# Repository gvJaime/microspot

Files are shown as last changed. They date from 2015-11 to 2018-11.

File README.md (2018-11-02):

# Microspot Project

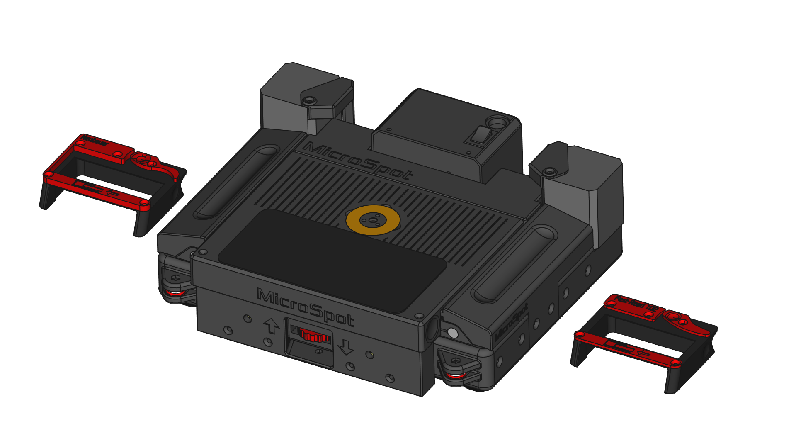
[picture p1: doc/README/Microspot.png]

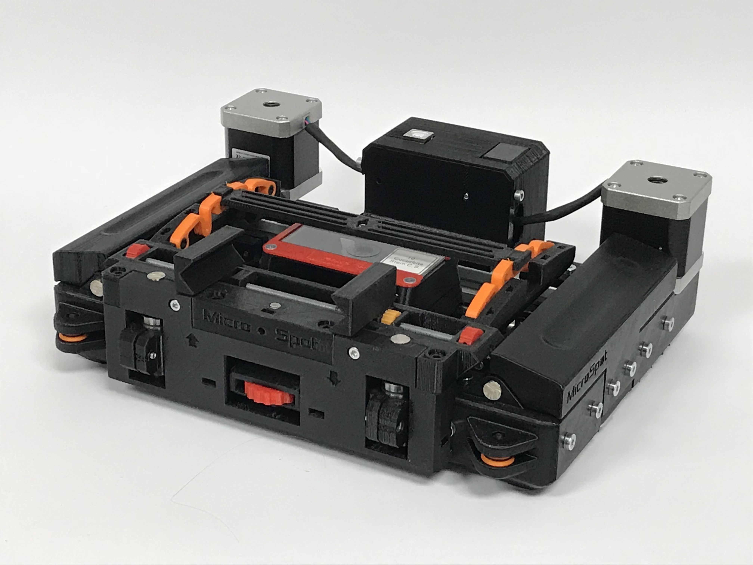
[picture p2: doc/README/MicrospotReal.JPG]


## Abstract

The purpose of this work is the development of a 3D printable, low cost, phone controlled, portable automated microscope that can be used to diagnose global health diseases anywhere in the world.

## The project

The device consists of a core-H mechanical stage, plus a vertical axis with a phone attached. The phone camera sees through an optical system that allows it to take pictures at a microscopic scale.

This project aims to bring medical diagnosis equipment to the open source community: Designs are made with 3D printing in mind, materials are inexpensive, and electronics accesible. The source is open from the very development stage, and the tools used to design it are open source.

This repo started as a collaboration between the Innovation and Robotics department of bq and the Technical University of Madrid, and it has been developed to a mature state within SpotLab S.L., but you can also contribute to it's development!

## Building the device

To build this device, you need to 3D print the objects indicated as "Printed" in the Assembly, and get all the items listed in the bill of materials.

+ Those groups labeled as PrintedStructural must be printed in a material that is considered suitable for structural applications. The rule of thumb is "the tougher the better".
+ Those groups labeled as PrintedTribologic must be printed in a material that holds at least some tribologic properties. They must present low friction.
+ Those gropus labeled as PrintedFlexible must be printed in flexible material.

The best way to understand how the device is made is to explore the Assembly file. Although, bill of materials and assembly instructions may be provided in the wiki.

## About this repository
This repository holds the mechanical information of the device, and wiki. Android app information and firmware information are held in other repos.

* `Mechanical`: [FreeCAD][FreeCADlink] files for the mechanical design
	* `src`: Source files in .FCStd format.
	* `Step`: Step files for component and auxiliar assembly import.
* `Optical` : Lens adapters approved on field.
* `Tools` : Tool parts that you may need for assembly or servicing.
* `Fonts`: Fonts used in the design of the parts.
* `doc`: useful files for documentation

### Contributing to this repository. Developer notes

You can contribute to this repo by forking it, and making pull requests to the [Development branch][Develop]. If you find problems to make the contribution this way, [place an issue][issue] and we'll work it out.

Due to FCStd files being unmergeable, Assembly.FCStd is modified only on the Development branch. It may not be included in pull requests.

**This repo relies heavily on [@hamish_2014 's Assemblyv2 workbench][Assemblyv2Link].** The assembly file is composed almost entirely of Assemblyv2 objects, every file has reference items that are imported dynamically using this workbench. **These files may not be usable if your FreeCAD distribution doesn't have this workbench installed.**

Also, there may be files that use [@DeepSOIC 's Lattice2 workbench][LatticeLink]'s Recompute locker. This may be used to avoid FreeCAD to recompute a whole file each time an operation is readjusted.

## History

### Microspot v0.1

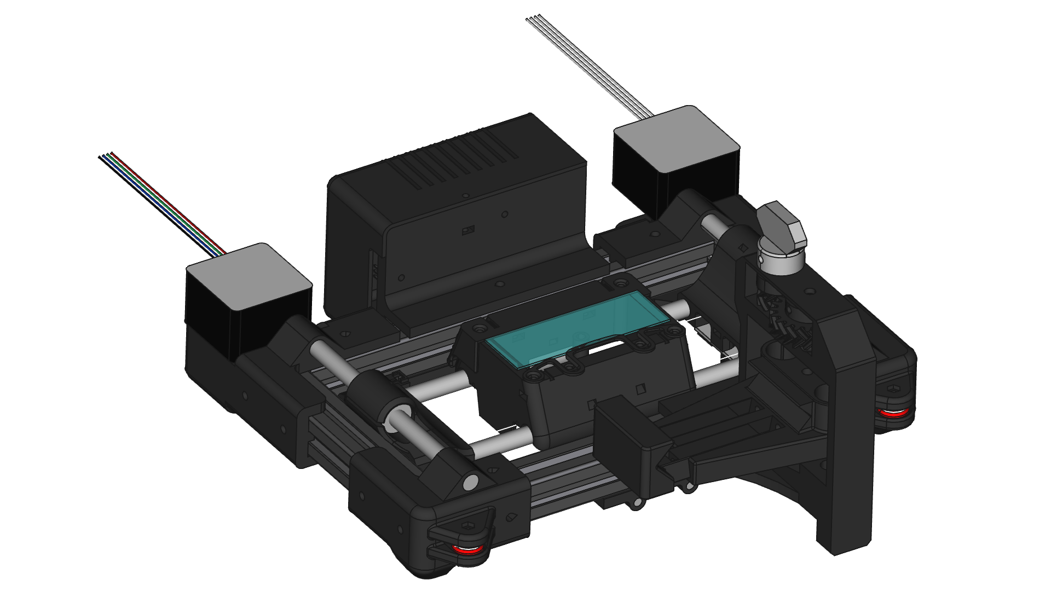
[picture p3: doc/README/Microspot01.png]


#### Changelog

+ Compact design, (256x256x130mm) for easy transport.
+ Aluminum profile + 3D printed parts based frame.
+ 2 axis core-H cartesian mechanical stage controlled by an Arduino, running [GRBL based firmware][microspot-fw].
+ 50x15mm scan area.
+ Integrated LED illumination system, with regulable intensity by firmware.
+ Phone support with adaptable grip, to fit all phone sizes.

### MicroSpot v0.2.1

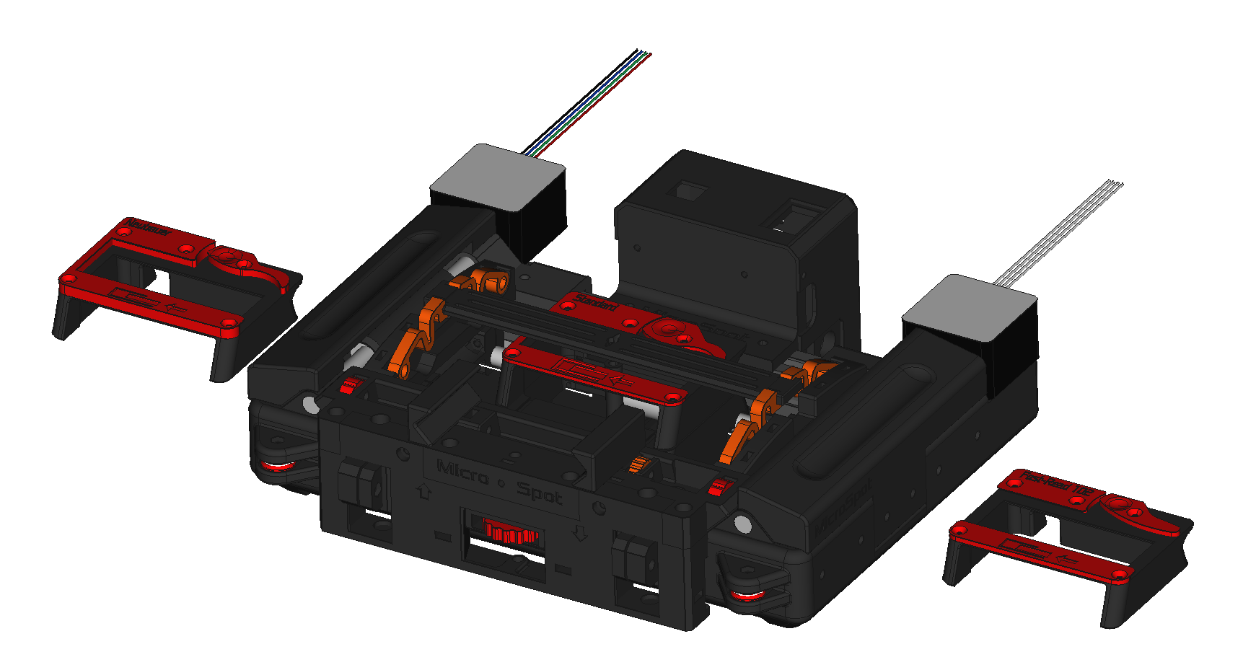
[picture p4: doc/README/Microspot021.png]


#### Changelog

+ New compact phone crane that doesn't stick forward, reducing size to 256x200x75
+ Lower plate protecting mechanical system.
+ Lens system adaptable for every phone.
+ New carriage design that allows for detachable sample trays.
+ Sample trays for standard samples, Neubauer samples, and more.
+ Sample fixing system revisioned.
+ General usability upgrades.

### MicroSpot v0.3

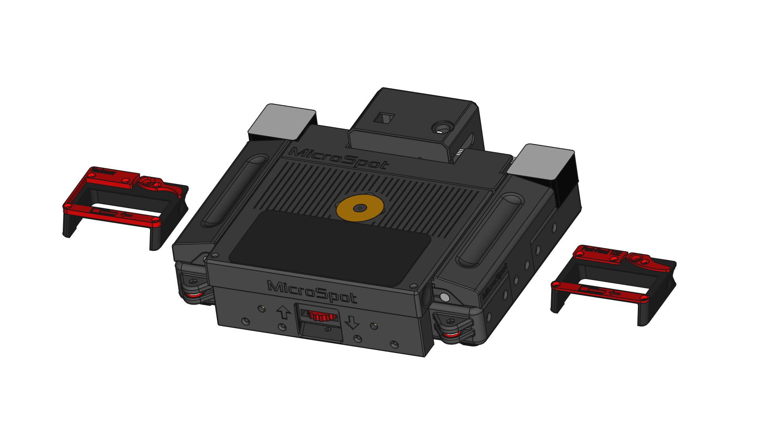
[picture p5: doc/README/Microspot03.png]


#### Changelog

+ New upper lid to protect the sample while scanning, featuring:
	+ New fixing system for the optics.
	+ New gel pad based fixing system for the phone.
	+ Openable by sliding forwards, allowing sample change without removing the phone.
	+ Stays closed by magnets.
+ Vertical axis revisioned.
	+ Printable linear guides, with BBs as bearings
	+ Updated knob, designed to minimize vertical backlash and ensure smooth movement.
+ Sample fixing system revisioned.
+ General assembly revisions.

### MicroSpot v1.0



#### Specs

+ New Optics system
	+ Capable of 10x.
	+ Tested on field.
+ New electronics.
+ General usability updates.
	+ New back lids that prevent mechanical damage to cables.
	+ Added On/Off switch.

## Credits

* SpotLab S.L. (Main Sponsor)
	* [@gvJaime](https://github.com/gvJaime) (Lead mechanical designer and integrator)
	* [@alexx666](https://github.com/alexx666) (Lead firmware programmer and connections coordinator.)
	* [@Dani-x2](https://github.com/Dani-x2) (Main Software Developer)
* Technical University of Madrid (Main concept & inspiration)
	* [@gvJaime](https://github.com/gvJaime) (Lead mechanical designer and researcher)
* Mundo Reader S.L (sponsor from October 2015 to April 2016)
	* [@gvJaime](https://github.com/gvJaime) (Lead mechanical designer and researcher)
	* [@AngelLM](https://github.com/AngelLM) (Mechanical designer. Wonderful teammate)

## License

Copyright (c) Universidad Politecnica de Madrid 2015

Licensed under Creative Commons 4.0 Attribution Share-Alike

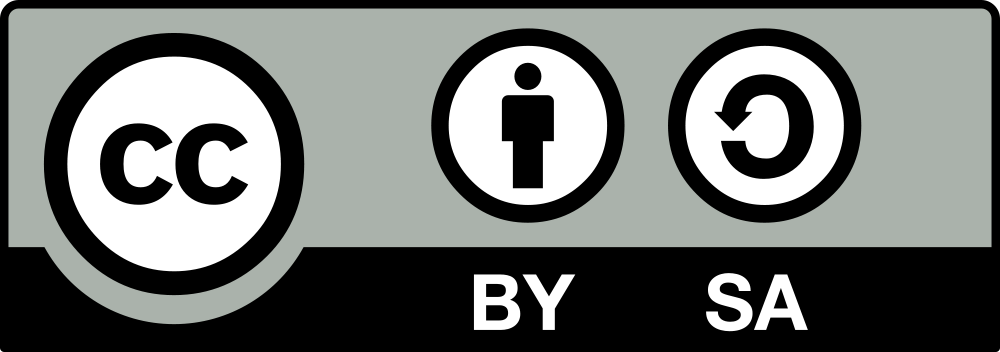
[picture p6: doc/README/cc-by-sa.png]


[FreeCADlink]: http://www.freecadweb.org/
[MalariaLink]: http://malariaspot.org/
[issue]: https://github.com/malariaspot/microspot/issues/new
[Develop]: https://github.com/malariaspot/microspot/tree/Development
[microspot-fw]: https://github.com/malariaspot/microspot-fw
[Assemblyv2Link]: https://github.com/hamish2014/FreeCAD_assembly2
[LatticeLink]: https://github.com/DeepSOIC/Lattice2

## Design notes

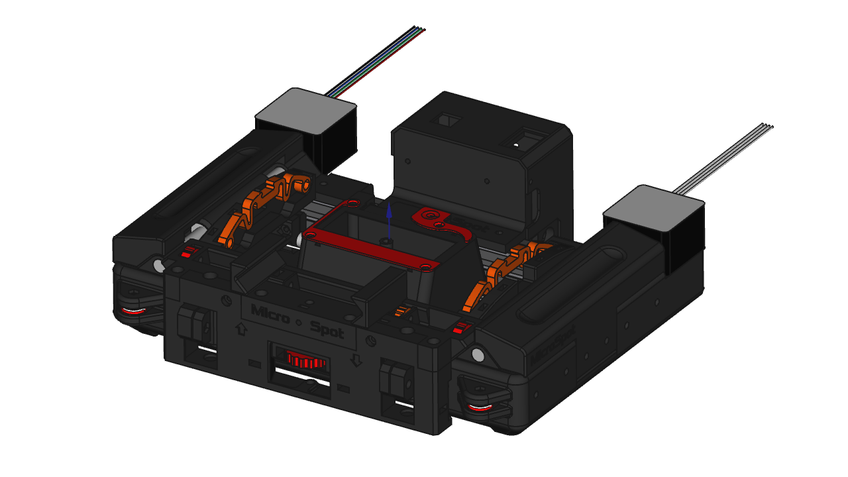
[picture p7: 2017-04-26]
doc/README/Microspot02.png

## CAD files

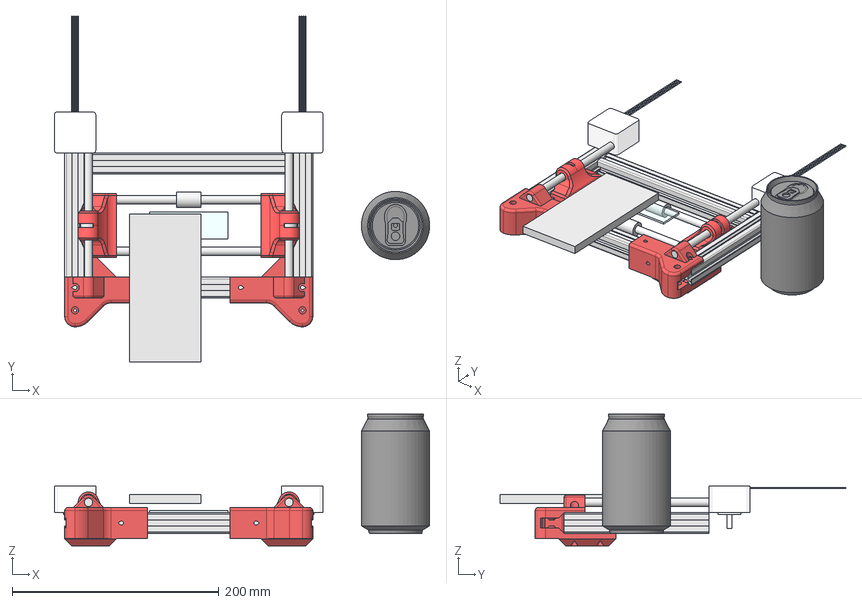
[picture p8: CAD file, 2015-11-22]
Mechanical/Assembly.fcstd
363.1 x 334.7 x 127.2 mm
T slot extrusion 20x20x200.001
T slot extrusion 20x20x140.001
Sample
bq Aquaris M5 Phone
4018X SNGL
YBar
XBar
LM8UU
LM8UU001
T slot extrusion 20x20x200.001 (Mirror #1)
T slot extrusion 20x20x140.001 (Mirror #2)
XBar (Mirror #4)
YBar (Mirror #5)
LM8UU (Mirror #6)
LM8UU001 (Mirror #7)
623ZZ (Mirror #9)
623ZZ (Mirror #10)
4018X SNGL (Mirror #3)
BeverageCan
623ZZ
623ZZ (Mirror #8)
Ycarriage
Ycarriage (Mirror #11)
IdlerHold
IdlerHold (Mirror #12)

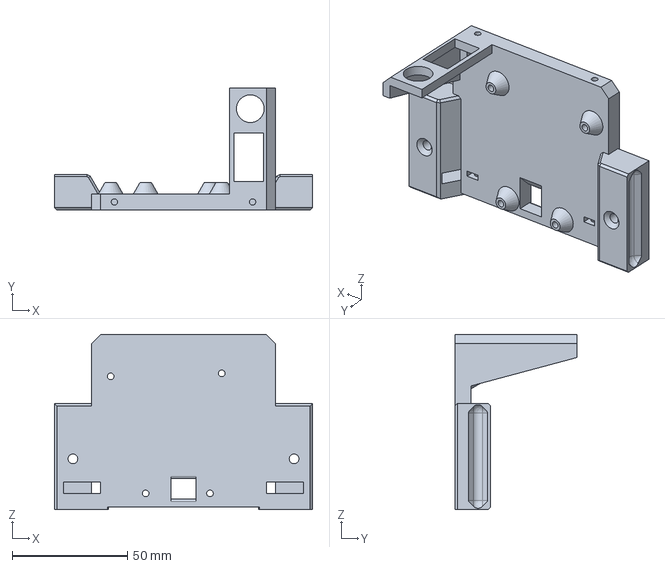
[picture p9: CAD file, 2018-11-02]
Mechanical/src/Electronics Holder/ElecMain.fcstd
112.0 x 53.0 x 76.0 mm

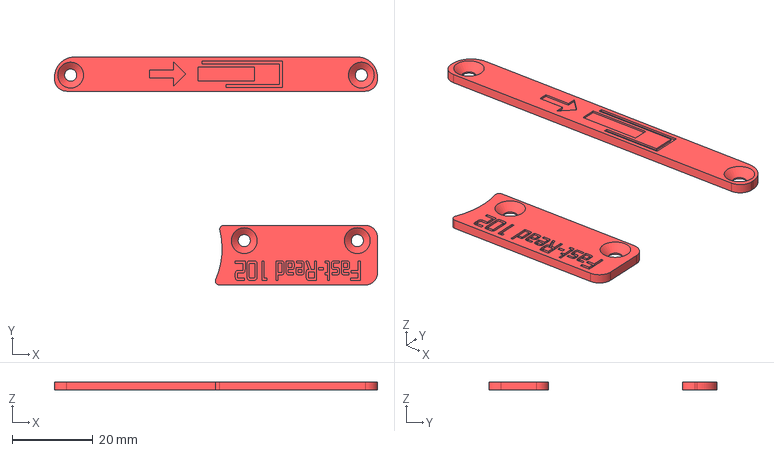
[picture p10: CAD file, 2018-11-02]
Mechanical/src/Axes/XCarriage/FastRead102/FastReadTop.fcstd
80.0 x 56.5 x 2.00 mm

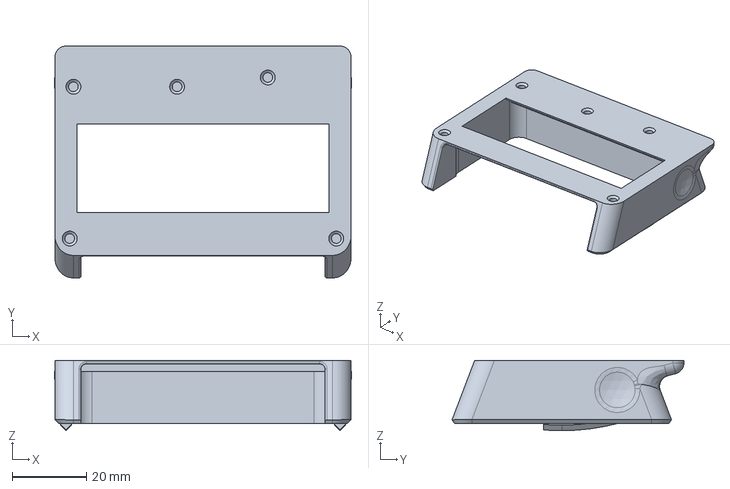
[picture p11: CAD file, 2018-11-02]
Mechanical/src/Axes/XCarriage/Neubauer/NeubauerTray.fcstd
80.2 x 62.6 x 19.0 mm

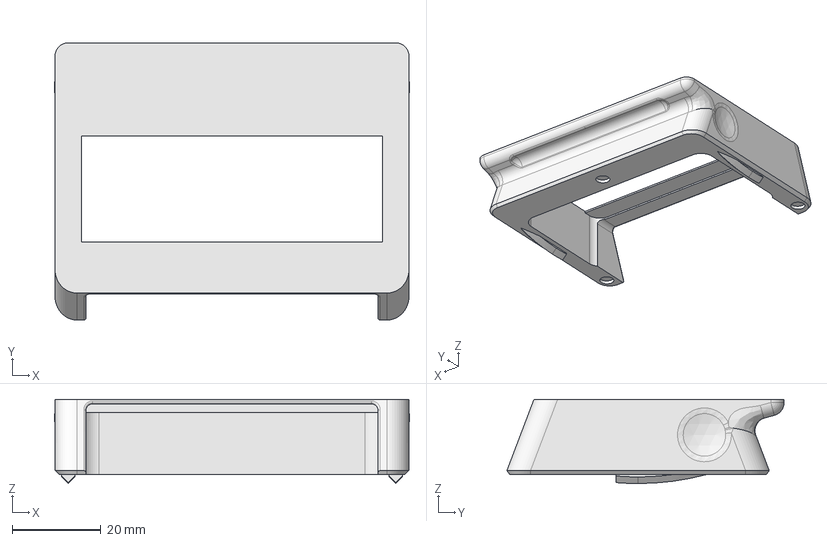
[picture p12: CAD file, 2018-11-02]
Mechanical/src/Axes/XCarriage/SampleTray.fcstd
80.2 x 62.6 x 19.0 mm

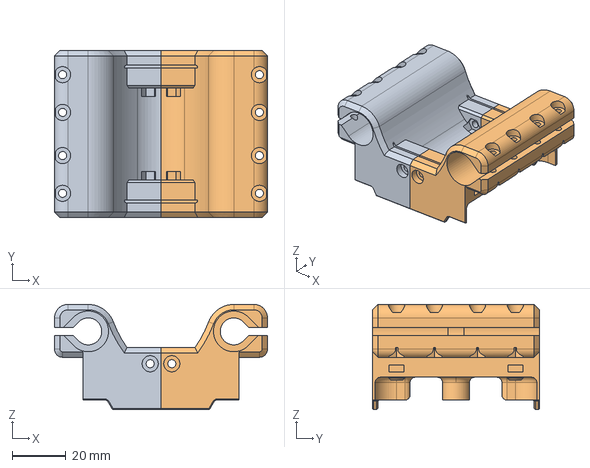
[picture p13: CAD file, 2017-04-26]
Mechanical/src/Axes/YCarriage/YCarriage.fcstd
79.0 x 62.0 x 39.0 mm
LYCarriage
RYCarriage

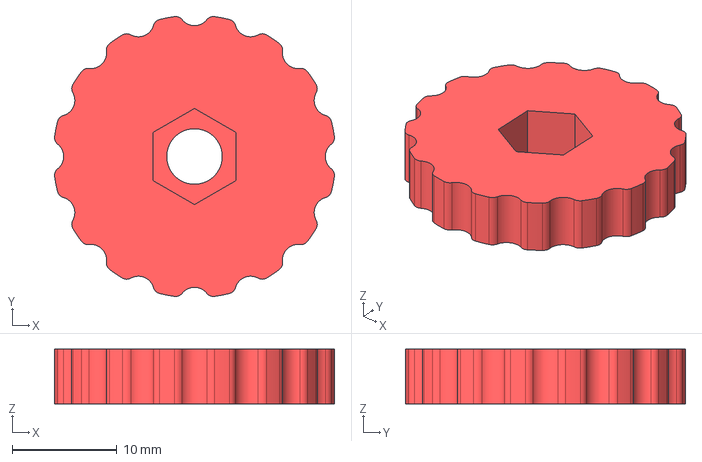
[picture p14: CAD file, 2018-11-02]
Mechanical/src/Axes/ZCarriage/FocusWheel.fcstd
26.7 x 26.7 x 5.25 mm

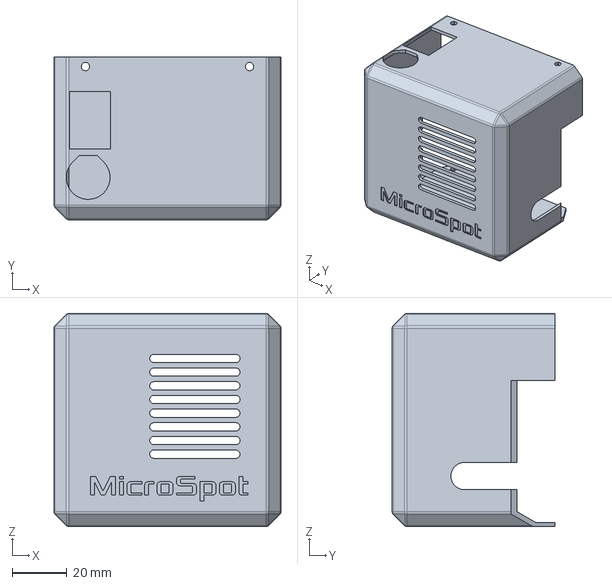
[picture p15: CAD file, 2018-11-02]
Mechanical/src/Electronics Holder/ElecLid.fcstd
83.0 x 59.5 x 78.0 mm

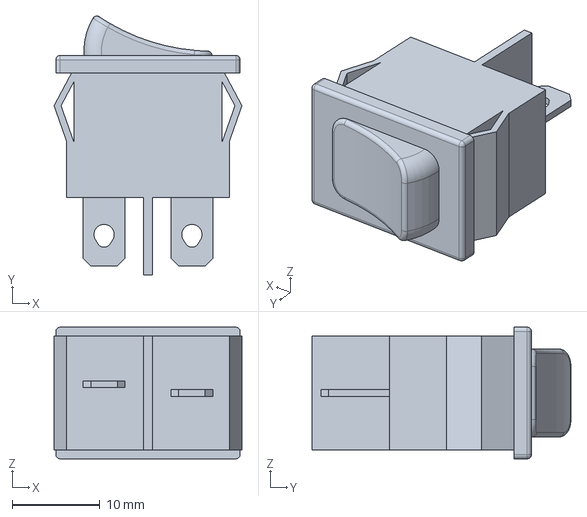
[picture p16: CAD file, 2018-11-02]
Mechanical/src/Electronics Holder/Reference/RLEIL RL3-4T125 55.fcstd
21.4 x 29.5 x 15.0 mm

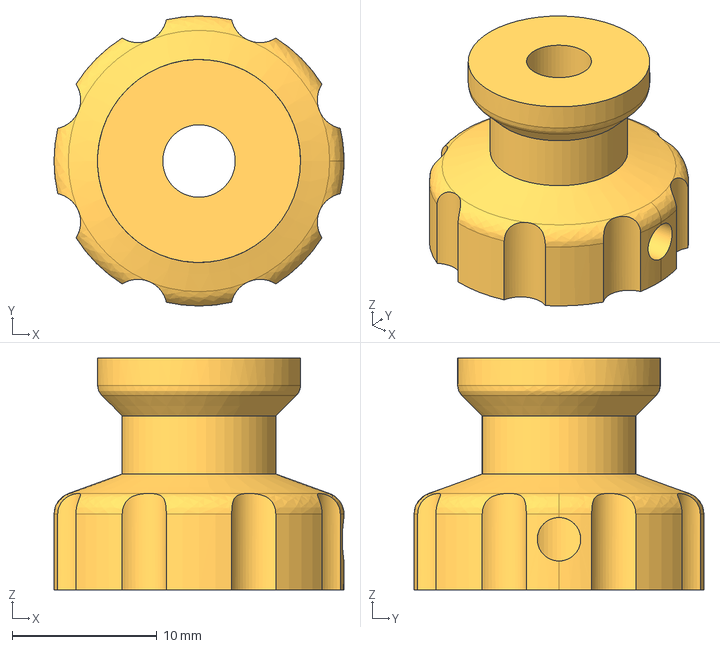
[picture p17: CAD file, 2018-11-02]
Mechanical/src/MainFrame/NEMAPulley.fcstd
20.0 x 20.0 x 16.0 mm

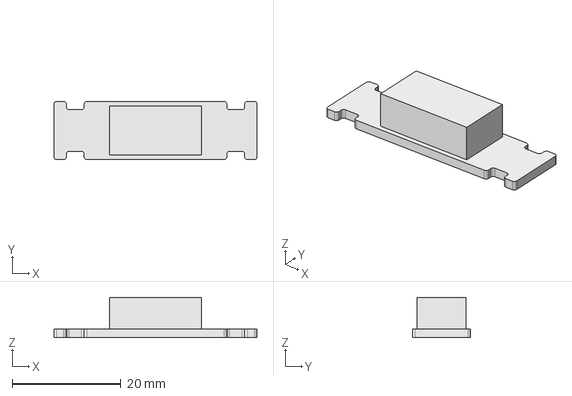
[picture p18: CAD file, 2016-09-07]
Mechanical/src/MainFrame/Reference/FemtoBuck.fcstd
37.4 x 10.7 x 7.38 mm

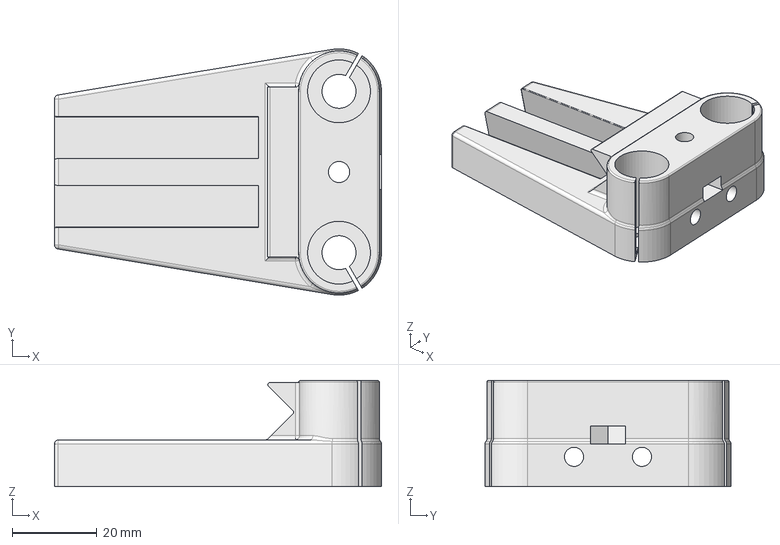
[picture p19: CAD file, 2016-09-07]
Mechanical/src/smartphoneHolder/PhoneCarriage.FCStd
77.0 x 58.0 x 25.0 mm

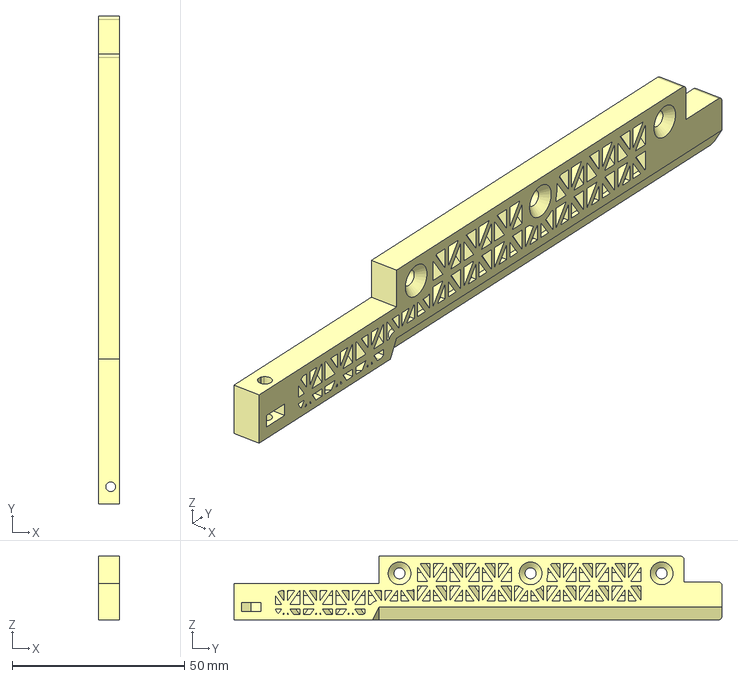
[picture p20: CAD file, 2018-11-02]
Mechanical/src/UpperLid/UpperLidRail.fcstd
6.00 x 141.5 x 18.5 mm

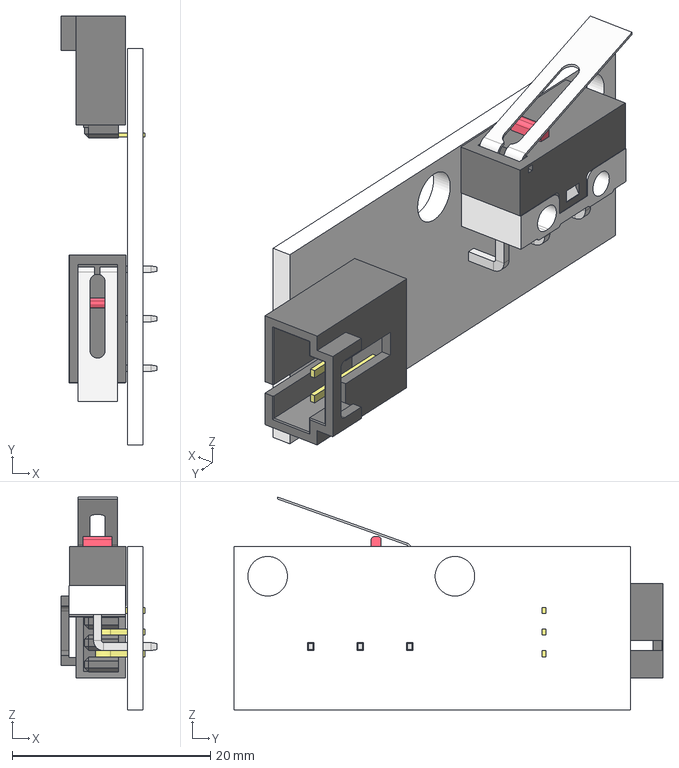
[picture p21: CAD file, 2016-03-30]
Mechanical/Step/Components/Endstop.step
9.70 x 43.3 x 21.5 mm

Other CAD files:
Mechanical/src/Axes/XCarriage/StdTray/StdTray.fcstd
Mechanical/Step/Printed/Axes/YCarriage/LYCarriage.step
Mechanical/Step/Printed/Axes/ZAxis/BackCraneGuide.step
Mechanical/Step/Printed/Electronics Holder/ElecBase.step
Mechanical/Step/Components/4018X SNGL.stp
Mechanical/Step/Components/NEMA8x13.step
Mechanical/Step/Printed/Axes/YCarriage/RYCarriage.step
Mechanical/Step/Printed/Axes/ZAxis/FrontCraneGuide.fcstd
Mechanical/Step/Printed/Axes/ZAxis/FrontCraneGuide.step
Mechanical/Step/Printed/Electronics Holder/Lid.step
Mechanical/Step/Printed/MainFrame/LAxisShield.step
Mechanical/Step/Printed/MainFrame/LBackCorner.step
Mechanical/Step/Printed/MainFrame/TubeLid.step
Mechanical/Step/Printed/PhoneHolder/Ratchet.step
Mechanical/Step/Printed/SmartphoneHolder/LPhoneGrip.step
Mechanical/Step/Printed/SmartphoneHolder/LowerPhoneCarriage.step
Mechanical/Step/Printed/SmartphoneHolder/RPhoneGrip.step
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

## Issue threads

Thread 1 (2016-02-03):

Y axis should have its bearings in triangle

elgambitero, 2016-02-03:
This prevents the carriage to lose perpendicularity with X axis

Closed 2016-02-15.

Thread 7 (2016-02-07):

NEMA doesn't fit in place

elgambitero, 2016-02-07:
The two metal frames are slightly wider than the plastic body that was taken as reference

Closed 2016-02-15.

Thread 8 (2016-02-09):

Front20Guide missing in IdlerHold

elgambitero, 2016-02-09:

Closed 2016-05-13.

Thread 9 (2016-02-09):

An UpperBolt missing in IdlerHold

elgambitero, 2016-02-09:

Closed 2016-05-13.

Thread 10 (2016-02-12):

Remodel Ycarriage in order to fix the bars to it better.

elgambitero, 2016-02-12:
It must feature a slot to let the plastic wrap around the smooth bar, tight.
It must feature a wall in the smooth bar hole, for it not to hit the idlers, and for ease of assembly.

Closed 2016-05-24.

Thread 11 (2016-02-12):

Rethink string lane geometries, in order to drive the string better upon assembly

elgambitero, 2016-02-12:
Make string size windows towards the pulleys. Idlers must be confined in a much smaller place. Idlers' geometry must trap the string, not letting it go that easily.

Something must be done to solve pulleys assembly. The string must be in tension all the time or it leaves the pulley!

Pulleys' shaft hole shape prevents it from going all the way down to the base of the NEMA and that's bad because the string can get trapped there if it unwraps the pulley.

elgambitero, 2016-05-10:
The new string configuration will take it through the center hole of the profiles, so we can use the outer surface for bolting. Also, that outer area doesn't have to be that thick.

With the extra bolts on the side, corners may be smaller, leaving more room for the phone crane to move.

So, motors have to be moved closer to each other, and also the front pulleys.

Closed 2016-06-08.

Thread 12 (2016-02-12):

Filaflex idlers could be absorbing some of the string tension.

gvJaime, 2016-02-12:

gvJaime, 2016-11-04:
This seems to be the reason there is a 0.2 mm backlash in the X axis.

gvJaime, 2017-01-18:
As it turns out, filaflex contributes for a smoother axis movement.

Closed 2017-02-17.

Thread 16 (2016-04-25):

Idler geometry doesn't hold the string in place

elgambitero, 2016-04-25:
String placement is extremely difficult.

elgambitero, 2016-05-24:
String placement is difficult for the FrontCorner idlers, but the YCarriage ones are just OK.
MainFrame remodellation may solve this.

elgambitero, 2016-06-08:
YCarriage idlers still suffer but assembly is acceptable. Making the pulleys larger could need mayor part update

Closed 2016-06-08.

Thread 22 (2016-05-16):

LEDTube is too narrow in its center part

elgambitero, 2016-05-16:

elgambitero, 2016-09-05:
With the new illuminator design, this issue doesn't make sense anymore.

Closed 2016-09-05.

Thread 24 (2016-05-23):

Decide a shape for smooth rod and bearing horizontal holes.

gvJaime, 2016-05-23:

gvJaime, 2016-10-04:
A good option is, the typical tear shape, but with an horizontal cut on the spike, at a distance from the center that is equal to the radius.

Closed 2016-10-20.

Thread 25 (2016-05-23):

PhoneCarriage needs to be iterated

elgambitero, 2016-05-23:

elgambitero, 2016-05-24:
M5 nut doesn't fit the slot.
Bearings sit with too much clearance, tighter slots and a expanding slit may solve the issue.
M3 threaded rod holes need to be wider in order to the rod passing through.
The platform needs to be longer. It will bend with bigger phones.

Closed 2016-06-08.

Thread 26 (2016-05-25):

When RYCarriage bearings are placed, they end up misaligned.

gvJaime, 2016-05-25:

elgambitero, 2016-05-25:
The bearing slit design tilts the bearings against the open side.

elgambitero, 2016-05-25:
With a little bit of sanding and 3D printing debris removal, this issue can be worked around.

Closed 2016-11-30.

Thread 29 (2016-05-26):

Light bounces on XCarriage inner walls and it may distort the image

elgambitero, 2016-05-26:

elgambitero, 2016-09-05:
With the install of the LED tube, this issue doesn't make sense anymore. Closing.

Closed 2016-09-05.

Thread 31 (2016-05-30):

Endstop bolt hole missing in BackCorner

elgambitero, 2016-05-30:

Closed 2016-06-10.

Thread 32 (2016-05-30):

Endstop bolt hole missing in BackCorner

elgambitero, 2016-05-30:

Closed 2016-05-30.

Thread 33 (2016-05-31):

Y Endstop pins collide with BackCorner.

gvJaime, 2016-05-31:

Closed 2016-10-07.

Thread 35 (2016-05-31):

String tensioner fixing bolt holes in XCarriage should be longer, not to require an excessive short bolt

elgambitero, 2016-05-31:

Closed 2016-05-31.

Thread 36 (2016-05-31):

Idlers collide with the cavity when spinning

elgambitero, 2016-05-31:

Closed 2016-06-08.

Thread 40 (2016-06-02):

Current string tensioner system can destroy the string.

elgambitero, 2016-06-02:

elgambitero, 2016-06-08:
Kevlar string can be crushed, but polyester string yields better results.

elgambitero, 2016-09-05:
Polyester strings doesn't break. It rather penetrates the threads of the nut, fixing itself in place.

Closed 2016-09-05.

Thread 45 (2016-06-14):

Electronics lid fixings are insufficient.

elgambitero, 2016-06-14:
The "one bolt" philosophy didn't quite work.

Closed 2016-06-20.

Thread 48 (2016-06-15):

Make PhoneCarriage reach lower positions.

elgambitero, 2016-06-15:
It must be able to almost collide with the sample, in cases of ball lens usage.

elgambitero, 2016-06-15:
Removing the upper cap, you can get the carriage 5mm lower in position

Closed 2016-07-06.

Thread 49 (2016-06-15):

SampleFix doesn't push hard enough against the sample

elgambitero, 2016-06-15:

Closed 2016-06-20.

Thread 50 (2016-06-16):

Make DVD lens adaptor for Aquaris X5

gvJaime, 2016-06-16:

elgambitero, 2016-06-16:
Aquaris X5 and Xperia X1 would be the first phones to recieve an adaptor design. For convenience.

elgambitero, 2016-06-17:
First print proved the design to be highly disfunctional

gvJaime, 2016-11-30:
Deprecated due to NewCrane

Closed 2016-11-30.

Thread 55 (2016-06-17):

Add bolts to XCarriage to guide SampleFix

elgambitero, 2016-06-17:

elgambitero, 2016-06-17:
Sample fix will need a redesign to accept this bolt usage.

Closed 2016-06-20.

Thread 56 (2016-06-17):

StringTensioner sample top is the wrong side.

gvJaime, 2016-06-17:

elgambitero, 2016-07-26:
This has turned up to be a problem upon usage in Mozambique.

Closed 2016-11-30.

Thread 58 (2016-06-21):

Phone Gears are placed too far from each other

elgambitero, 2016-06-21:

elgambitero, 2016-06-21:
This produces backlash, and hysteresis between the pinion spin and the vertical placement

elgambitero, 2016-06-22:
Bringing the gears too close together can led to jams.

Closed 2016-07-06.

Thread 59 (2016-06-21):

Phone gears' nut slot is too wide and lets the nut spin freely.

elgambitero, 2016-06-21:

Closed 2016-06-22.

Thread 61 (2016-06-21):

DVD2Xperia's camera hole is too high

elgambitero, 2016-06-21:

Closed 2016-06-22.

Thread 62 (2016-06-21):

PhoneHolder threaded rods need thumbscrews

gvJaime, 2016-06-21:

elgambitero, 2016-06-22:
Making the hole wider to meet tight tolerances was a mistake, because Slic3r already corrects this.
Making the hexagon dimensions nominal.

Closed 2016-11-30.

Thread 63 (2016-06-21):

When spinning, Phone gears teeth collide.

elgambitero, 2016-06-21:

elgambitero, 2016-06-21:
This will be tested when the new gears are properly printed.

Closed 2016-06-29.

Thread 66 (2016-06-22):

Make experimental scope with the two BluRay lenses

gvJaime, 2016-06-22:

elgambitero, 2016-06-22:
Refractive indices are needed for proper calculation.

elgambitero, 2016-06-22:
In case of not having proper index measurements, consider making a focusing mechanism, modifying the distance between the two lenses.

gvJaime, 2017-05-22:
This issue has been obsoleted by the preference of stock lenses, and the new "Snell law" command.

Version 0.3 issue #180 already counts on this.

Closed 2017-05-22.

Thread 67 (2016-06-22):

Make phone gears shaft emerge from protuberances, so the gears get aligned.

elgambitero, 2016-06-22:
Also, a little bit of friction could provide a more uniform progression of the axis, and give it strength not lose position because of vibrations.

Closed 2016-07-06.

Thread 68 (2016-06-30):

Update crane design to allow a Z motor to be installed.

elgambitero, 2016-06-30:
This is an update of the original design by @AngelLM, rather than a complete redesign needed for #54

Closed 2016-07-05.

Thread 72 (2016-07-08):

Illuminator doesn't fit between XCarriage domain and the ground

elgambitero, 2016-07-08:
Zip-ties collide
Min and Max Xcarriage points make endstop flaps collide.
Bolts collide with the floor, even when the stick out just the width of a nut.

Closed 2016-07-12.

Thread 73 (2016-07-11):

Xcarriage endstop flaps collide with illuminator

elgambitero, 2016-07-11:
They can be made 1 or 2 millimeters shorter, without compromising their function

Closed 2016-07-12.

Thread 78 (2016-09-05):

Add a lower panel to protect the axes and the string.

gvJaime, 2016-09-05:

elgambitero, 2016-09-05:
That could require, and benefit from, a complete frame redesign.

Closed 2016-10-07.

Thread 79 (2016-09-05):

Make multiphone adaptor for various lenses

elgambitero, 2016-09-05:

elgambitero, 2016-09-05:
It must have a sliding lens mount, so the user can select between various magnifications.
It must fit every phone (this is, every width, every thickness, and every camera position)

elgambitero, 2016-09-05:
A flexible design could be the solution, but that may give some difficulties with 3d printing, and durability of the part.

gvJaime, 2016-10-27:
The design is hard to print, and nails disassemble by themselves.

gvJaime, 2016-11-03:
See #105

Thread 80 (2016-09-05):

Redesign frame to make assembly easier

gvJaime, 2016-09-05:

elgambitero, 2016-09-05:
The assembly must be obvious, and must not require special skill.  It must be easily repeatable.

elgambitero, 2016-09-19:
The main difficulties of the current assembly are: fitting the two halves, and putting the string in place. The latter is way more complicated than the former.

Closed 2017-01-18.

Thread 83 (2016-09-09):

Attaching and adjusting the phone crane is painfully difficult

gvJaime, 2016-09-09:

gvJaime, 2016-12-09:
The new phone crane solved this issue. Disassembly is no longer needed before packaging the device.

Closed 2016-12-09.

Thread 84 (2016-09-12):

1mm Xperia adapter is too thin, and may slip or break

gvJaime, 2016-09-12:

Closed 2016-10-07.

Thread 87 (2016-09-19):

MainStructure of the phone holder won't reach the floor.

gvJaime, 2016-09-19:
Now that the MicroSpot frame is 3mm higher, this needs adjustment.

gvJaime, 2016-10-13:
With the new crane, this condition is no longer needed.

Closed 2016-12-09.

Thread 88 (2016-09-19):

Light is uneven across the field

gvJaime, 2016-09-19:
A flare that washes out the image can be seen through the sample. It is the center of the LED light source.

gvJaime, 2016-10-24:
Could a cigarette filter smooth the lightning enough?

Closed 2017-11-20.

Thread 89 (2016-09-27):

CNCShield doesn't power up the arduino

gvJaime, 2016-09-27:
This is a CNCShield design decision rather than a bug, but for MicroSpot is inconvenient because this make us rely on the phone to power up the arduino.

As tests with the OnePlus Two reveal, not every phone allows to output power over USB.

gvJaime, 2018-02-06:
A connecting the Vin Pin directly to 12V could work, but it would stress the voltage converter of the board.

gvJaime, 2018-11-05:
With the addition of Sparkfun's redboard, this is not an issue anymore.

Closed 2018-11-05.

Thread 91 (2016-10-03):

StringTensioner bolt needs another point of support

gvJaime, 2016-10-03:
The current setting results in backlash.

Closed 2016-11-30.

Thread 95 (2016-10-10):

MCNail in MultiClaw won't fit the rail.

gvJaime, 2016-10-10:

gvJaime, 2016-11-30:
Deprecated due to NewCrane

Closed 2016-11-30.

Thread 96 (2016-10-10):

MCGrip rail's walls are too thin

gvJaime, 2016-10-10:

gvJaime, 2016-11-30:
Deprecated due to NewCrane

Closed 2016-11-30.

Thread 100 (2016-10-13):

MainStructure doesn't fit for centered camera phones

gvJaime, 2016-10-13:
as v2Preview asssembly file reveals

gvJaime, 2016-11-30:
Deprecated due to NewCrane

Closed 2016-11-30.

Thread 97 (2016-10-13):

MechEndstop board sourcing is too difficult

gvJaime, 2016-10-13:
LBackCorner redesign might be in order, given the fact that it adjust to the board and the conector

gvJaime, 2016-10-13:
Migration to raw switches may need the edition of LBackCorner, RYCarriage, and in the event of changing the center position, the LowerCover

Closed 2016-11-14.

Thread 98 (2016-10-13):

MainStructure bolt orientation is wrong

gvJaime, 2016-10-13:

Closed 2016-10-20.

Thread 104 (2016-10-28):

Light tube is too short

gvJaime, 2016-10-28:

Closed 2016-12-02.

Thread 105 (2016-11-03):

Lenses must be fixed to PhoneCarriage

gvJaime, 2016-11-03:
The lens doesn't have horizontal degrees of freedom when it's on focus, so there is no reason  for it to be attached to the phone.

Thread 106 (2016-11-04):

YCarriage print errors can produce axis skewing

gvJaime, 2016-11-04:
Leaving the bearing cavity open, to fix with a zip tie could be a solution

Closed 2016-12-20.

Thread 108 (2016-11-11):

Lens adjustment mechanism is counter intuitive, and easy to get wrong

gvJaime, 2016-11-11:

gvJaime, 2016-12-09:
This mechanism has been dropped and substituted for a new spring mechanism.

Closed 2016-12-09.

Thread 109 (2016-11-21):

PhoneCarriage's clearances cause variation on the phone's pitch.

gvJaime, 2016-11-21:

Closed 2016-12-09.

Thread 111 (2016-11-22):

Lens crane ends up getting too close to the phone, and that renders the crane unusable for bigger phones

gvJaime, 2016-11-22:

Closed 2016-12-09.

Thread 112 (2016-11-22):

Lens crane SmallLongArms collide with OpticFit

gvJaime, 2016-11-22:

Closed 2016-11-28.

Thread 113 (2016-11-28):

YCarriage rod slots need a bit of clearance in the end

gvJaime, 2016-11-28:
Bridging dimensions errors end up misaligning the Y axis bearings with the rod

Closed 2016-11-30.

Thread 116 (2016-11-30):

AxisShield collides with NEMA motors

gvJaime, 2016-11-30:

Closed 2016-12-02.

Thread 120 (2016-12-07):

Holding each YCarriage bearing with two zipties could help prevent Axis skewing.

gvJaime, 2016-12-07:
The current setting allows for a small spin

gvJaime, 2016-12-07:
That won't help. See #124

Closed 2016-12-07.

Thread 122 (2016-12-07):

Replace PhoneCarriage dies with flexible filament structures

gvJaime, 2016-12-07:

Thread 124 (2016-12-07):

Redesign YCarriage so it completely attaches to the LM8UUs

gvJaime, 2016-12-07:

Closed 2016-12-20.

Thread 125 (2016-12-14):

Easily interchangeable light tube

gvJaime, 2016-12-14:

gvJaime, 2016-12-30:
A  joint between two printed parts could let light escape, and contaminate the image captured by the camera.

Light tube customization will be limited to adapters.

Closed 2017-01-11.

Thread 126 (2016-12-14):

Increase collimation in TubeLid

gvJaime, 2016-12-14:

gvJaime, 2016-12-28:
The TubeLid could be replaceable, or maybe an adaptor could fit in the tip.

Narrow holes are incredibly tricky to print, as backlash and belt elasticity factors become dominant in dimension stability.

gvJaime, 2016-12-30:
See first comment in #125. Tip adapters are the best option right now.

Closed 2017-01-11.

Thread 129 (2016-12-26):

NEMA Pulley needs dimensional accuracy beyond regular 3D printing capabilities

gvJaime, 2016-12-26:

gvJaime, 2016-12-30:
Maybe an SLS could get to that dimensional stability, but, if that it's not an option, we could consider a calibration mechanism, in which you calibrate the steps per mm with a template.

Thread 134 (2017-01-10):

Lens Mount doesn't fit the bracket.

gvJaime, 2017-01-10:

Closed 2017-01-11.

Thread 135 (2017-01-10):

Make Lens mount 1mm shorter so the brackets end up aligned.

gvJaime, 2017-01-10:

Closed 2017-01-12.

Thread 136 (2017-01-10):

Bracket bolts collide with XCarriage

gvJaime, 2017-01-10:

Closed 2017-01-13.

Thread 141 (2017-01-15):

FlexiLens crane collides with USB cable, when the port is on the side of the phone.

gvJaime, 2017-01-15:

gvJaime, 2017-01-18:
The elliptical curve could be lowered the crane doesn't lose it's style lines.

Closed 2017-01-30.

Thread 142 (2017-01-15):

Bracket holes need more clearance

gvJaime, 2017-01-15:

Closed 2017-01-16.

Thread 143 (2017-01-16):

ElecLid doesn't leave space for wires

gvJaime, 2017-01-16:

Closed 2017-01-16.

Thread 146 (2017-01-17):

ElecBase Lid bolt holes need to be tighter

gvJaime, 2017-01-17:

Closed 2017-01-30.

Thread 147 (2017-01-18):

PhoneGrip thumbwheels have their functions coupled

gvJaime, 2017-01-18:
There should be one for tightening the grips, and another one for horizontal displacement

gvJaime, 2017-01-18:
A displacement thumbwheel can be put in place, where the M4 nuts go.

Closed 2017-01-24.

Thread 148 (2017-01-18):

Samples are a bit hard to put in place when the phone doesn't have the camera on the right.

gvJaime, 2017-01-18:

Closed 2017-11-20.

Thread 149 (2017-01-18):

The electronics box could have an on/off switch.

gvJaime, 2017-01-18:

gvJaime, 2017-01-25:
Issue has been dismissed for v2 due to lack of space in the electronics box

Closed 2017-02-13.

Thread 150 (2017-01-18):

XCarriage's string tensioner bolt hole must be very tight

gvJaime, 2017-01-18:

Closed 2017-01-30.

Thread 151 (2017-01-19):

XCarriage tensioner needs to be tighter

gvJaime, 2017-01-19:

Closed 2017-01-19.

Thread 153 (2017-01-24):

When made of FilaFlex, LensBracket doesn't hold the weight of LensMount

gvJaime, 2017-01-24:

Closed 2017-01-30.

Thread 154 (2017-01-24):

Left PhoneGrip loses adjustment when the threaded rod spins.

gvJaime, 2017-01-24:

gvJaime, 2017-01-24:
The user may have to prevent it's spinnning by pressing the wheel with the finger

Closed 2017-02-17.

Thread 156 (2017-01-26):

Given that camera-lens distance is not that critical, Lens should be fixed to PhoneCarriage

gvJaime, 2017-01-26:

gvJaime, 2017-02-20:
This also allows for a multiple lens revolver.

Closed 2017-04-27.

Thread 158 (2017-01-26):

String tensioner needs urgent rework

gvJaime, 2017-01-26:

gvJaime, 2017-01-26:
If the string is going to be replaced with a belt, thread locker may be the solution for now.

Closed 2017-01-30.

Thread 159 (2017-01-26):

Make XCarriage for belt driven version

gvJaime, 2017-01-26:

gvJaime, 2017-02-14:
Adapting microspot to a belt won't be limited to a simple XCarriage mod. RYCarriage will need an edit also.

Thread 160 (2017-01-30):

LensBracket collides with PhoneCarriage, when on the lower position.

gvJaime, 2017-01-30:

Closed 2017-01-31.

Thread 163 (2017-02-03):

Fillet missing in LensMount

gvJaime, 2017-02-03:

Closed 2017-02-07.

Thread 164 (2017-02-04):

M3 nut doesn't fit FrontCorner

gvJaime, 2017-02-04:

Closed 2017-04-26.

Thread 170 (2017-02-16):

The crane needs a coarse position adjustment

gvJaime, 2017-02-16:
Spinning the position wheels to switch between phones is too much of a hassle.

gvJaime, 2017-02-16:
The new PhoneGrip will have a dovetail locker in one claw, and the other claw will have a DIN933 in a thumbscrew, connected to the first claw by a nut.

DIN933 length is to be discussed. It must not stick out when completely screwed.

Closed 2017-04-26.

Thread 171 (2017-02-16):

ElecMain sign doesn't print well.

gvJaime, 2017-02-16:

Closed 2017-11-20.

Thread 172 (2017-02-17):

ElecLid has SwitchWindow misaligned

gvJaime, 2017-02-17:

Closed 2017-04-26.

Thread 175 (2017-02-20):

The crane still tilts. Depends heavily on LM8UU tightness.

gvJaime, 2017-02-20:

gvJaime, 2017-02-20:
Maybe this axis is eligible for friction bearing usage. It has little to no travel distance, and it's slow.

gvJaime, 2017-02-28:
PTFE preloaded bearings may help a lot.

gvJaime, 2017-02-28:
Also, BearingHolder's  bearings need to be put in place with front bolts. Current setup bends, and that damages the crane's rigidity.

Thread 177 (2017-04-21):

Use a milled aluminium frame as a base for all the parts, Prusa i3 style

gvJaime, 2017-04-21:
That would prevent axis not-orthogonality, because we could preassume that the frame is carefully milled, and distances and directions are OK.

gvJaime, 2018-11-05:
As a maker project, this is not possible anymore.

Closed 2018-11-05.

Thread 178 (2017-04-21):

In case of using a dovetail lane for the phonefix, make a lock like in Sunrise

gvJaime, 2017-04-21:
The lock would consist in a small threaded element, that when spinned, would press the dovetail up, locking it in place.

gvJaime, 2018-11-05:
The pad made PhoneFix unnecessary, so let's close this.

Closed 2018-11-05.

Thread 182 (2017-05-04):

New sample loading system

gvJaime, 2017-05-04:
the sample must be loaded from under the phone. The carriage must have a sample tray attached by magnets, that the user can take out, secure the sample on, and attach again easily.

gvJaime, 2017-06-07:
SampleFix must click when the sample is properly put in place.

A wall attached to ElecBase could prevent the user from trying to attach the SampleTray from the wrong angle.

Closed 2017-11-20.

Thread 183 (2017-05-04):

New UpperCase

gvJaime, 2017-05-04:
Upper case with fixed EyePiece, PhoneFix, and focus wheel.

gvJaime, 2017-12-11:
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 [Solve that](https://trello.com/c/BMLLImGQ/1-solve-that)

gvJaime, 2017-12-14:
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 [MicroSpot v0.3](https://trello.com/c/mw9MjeaE/8-microspot-v03)

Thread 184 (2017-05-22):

Set optic specs with a semisphere lens, of version 0.2

gvJaime, 2017-05-22:

gvJaime, 2017-05-23:
The main parameter to begin the calculations, is the fact that:
```
An iPhone 6, with digital zoom to the max, at 80mm of an object, displays the object 4,2 times bigger on the screen.
```

Therefore, for now on, magnifications will be calculated so that the final image is produced 80mm in front of the phone camera.

gvJaime, 2017-06-01:
BK7 hemisphere of 3mm (n=1.517 for 582nm) is close enough, and it's in the catalog.

gvJaime, 2017-12-14:
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 [MicroSpot v0.3](https://trello.com/c/mw9MjeaE/8-microspot-v03)

Closed 2017-06-07.

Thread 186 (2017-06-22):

SampleTray 0.3 flap is too long

gvJaime, 2017-06-22:
It wouldn't be nice that it stuck out during a scan.

gvJaime, 2017-12-14:
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 [MicroSpot v0.3](https://trello.com/c/mw9MjeaE/8-microspot-v03)

Closed 2017-11-20.

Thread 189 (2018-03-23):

Yrod bolts collide with Yrod

gvJaime, 2018-03-23:

gvJaime, 2018-04-02:
Affected parts:
-FrontCorners
-BackCorners

gvJaime, 2018-04-02:
71e2ac65e6f7e5e9b5eef439a1849c9244f63eef fixes this

Closed 2018-04-09.

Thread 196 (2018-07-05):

Z axis pitches towards ElecBase, and the back jams when going up.

gvJaime, 2018-07-05:
The mechanics involved in this issue are unclear, but the cause seems to be clearly the tilt.

The proposed solution is a spring supported on the back profile that pushes UpperBackCover up. It would be guided by a long DIN912 M4, fixed with a hammerhead nut to the middle of the back profile, and would be containted entirely inside UpperBackCover when totally compressed.
Said spring is in my table right now.

gvJaime, 2018-11-05:
Proper printing and assembly solve this issue

Closed 2018-11-05.

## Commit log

2015-10-26 Make design of a parabolic lens mold. 10 in diameter, 1 mm in height
    [Test.stl, TestLens10_1.fcstd]
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2015-11-02 Add OpenSCAD spherical lens generation file, and some examples
    [Sphere1.stl, Sphere2.stl, Sphere3.stl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]
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2015-11-04 Progress in the development of a target structure
    [Assembly.fcstd]
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2015-11-04 Make LM8UU outer shell slimmer. Add part into assembly
    [Assembly.fcstd, Ycarriage.fcstd]
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2015-11-16 Make design of a more flat lens, taking advantage of the resin's viscosity in order to keep the center wet during post-curing
    [Pancake.scad, Pancake6.stl]
2015-11-17 Make design of a lens, and it's negative in order to stick them toghether with resin.
    [Cemented.scad, Cemented.stl, CementedNeg.stl]
2015-11-22 Make first design of the front corners. Add corners into assembly
    [Assembly.fcstd, IdlerHold.FCStd]
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2015-12-22 Make design of auxiliar holders for optical drive lens experiments
    [BluRay1LensHolder.stl, BluRay2LensHolder.fcstd, BluRay2LensHolder.stl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]
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2015-12-29 Finish the design of the PulleyCover part. Add part into assembly
    Conflicts:
    Mechanical/PulleyCover.FCStd
    [Assembly.fcstd]
2015-12-29 Fix missing PulleyCover source file
    [PulleyCover.FCStd]
2015-12-29 Refactor IdlerHold design. Add new design into assembly
    [Assembly.fcstd, IdlerHold.FCStd]
2015-12-29 Make design of the small pulleys on the YCarriage. Add them into assembly
    [Assembly.fcstd, MiniIdler.fcstd]
2015-12-29 Fix PulleyCover collition with YCarriage
    [Assembly.fcstd, PulleyCover.FCStd]
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2015-12-29 Make design of an optional shield to protect the Y axis
    [Assembly.fcstd, AxisSheld.fcstd]
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2016-01-27 Make design of a pulley that connects the NEMA and the string
    [NEMAPulley.fcstd]
2016-01-27 Fix bolts in PulleyCover
    [PulleyCover.FCStd]
2016-01-27 Restyle IdlerHold, and fix bolt dimensions
    [IdlerHold.FCStd]
2016-02-04 Put 3 bearings, and make more clearance for profiles and wire bearings in Ycarriage
    [Endstop.step, Ycarriage.fcstd]
2016-02-06 Remake the AxisEnd cut of PulleyCover. Turn printable bolt s into tear bolts
    [PulleyCover.FCStd]
2016-02-06 Reshape printable bolts into tear bolts in IdlerHold
    [IdlerHold.FCStd]
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2016-02-08 Add a bolt hole in IdlerHold, to fix the endstop
    [IdlerHold.FCStd]
2016-02-08 Make placefor a NEMA17 in PulleyCover. Make profile guides for easier assembly
    [PulleyCover.FCStd]
2016-02-08 Add profile guides to IdlerHold in order to make assembly easier
    [IdlerHold.FCStd]
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2016-02-19 MotorHolder fix
2016-03-30 Revert "Smartphone holder fix"
    [Assembly.fcstd, AxisShield.fcstd, Endstop.step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]
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2016-04-19 Make sketch of 100x with balls of n=1,3
    [Snell.fcstd]
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2016-04-19 Make a lensing cannon with BK7 and sapphire balls
    [Bk7_n_sapphire.fcstd, Snell.fcstd]
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2016-04-19 Make design of an adaptor, that keeps lenses and camera in contact
    [bk7saphContact.fcstd]
2016-04-19 Several calculations made with Pablo and Maria's assistance
    [1mm3mm assist.fcstd, PabloAdapter.fcstd, PabloContact.fcstd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]
2016-04-19 Figure out how the 1mm ball works, and make a compound scope with 2 3mm balls
    [1mm.fcstd, Dual.fcstd, Dual3mm.FCStd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]
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2016-04-25 Add Endstop hit, smooth rod ends, and smooth rod slits to YCarriage
    [LYcarriage.step, RYcarriage.step, Ycarriage.fcstd]
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2016-04-28 Correct Assembly relative links
    [Assembly.fcstd]
2016-05-04 Add countersunk bolts and string fixings
    [Xcarriage.fcstd]
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2016-05-04 Make bendable fixer for samples
    [SampleFix.fcstd]
2016-05-10 Modify string path to pass through the center of the profiles. Change endstops
    [Assembly.fcstd]
2016-05-11 Make design of a new idler that doesn't let go the string
    [FrontIdler.fcstd]
2016-05-11 Redesign IdlerHold. Rename it to FrontCorner
    [FrontCorner.fcstd, IdlerHold.FCStd]
2016-05-13 Redesign PulleyCover, rename it to BackCorner
    [FrontCorner.fcstd, PulleyCover.FCStd]
2016-05-13 Redesign NEMAPulley.
    [NEMAPulley.fcstd]
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2016-05-13 Update Assembly. Fix FrontIdler
    [Assembly.fcstd, FrontIdler.fcstd]
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2016-05-18 Add groove to MainStructure to avoid teeth collition
    [MainStructure.fcstd]
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2016-05-19 Redesign MainStructure to make space for the new holder
    [LowerLid.step, MainStructure.fcstd, MainStructure.step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]
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2016-05-20 Update LateralAdjust design and style, renamed to PhoneGrip. Update dependent parts to fit
    [MainStructure.fcstd, MainStructure.step, PhoneCarriage.FCStd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]
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2016-05-20 Correct errors in MainStructure
    [Assembly.fcstd, MainStructure.fcstd, MainStructure.step]
2016-05-23 Update Assembly with sample fix
    [Assembly.fcstd, SampleFix.fcstd]
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2016-05-24 Address the issues commented in issue #25
    [PhoneCarriage.FCStd, PhoneGrip.fcstd]
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2016-05-30 Correct 3d model corruptions in BackCorner. Update part.
    [LBackCorner.step, RBackCorner.step]
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2016-05-31 Update BackCorner to address issues #33 and #31
    [LBackCorner.step, RBackCorner.step]
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2016-05-31 Update XCarriage to close issue #35
    [Xcarriage.fcstd]
2016-06-01 NEMAPulley modified to address issue #38
    [NEMAPulley.fcstd]
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2016-06-10 Close issue #43: Turn threaded rods from M3 to M4
    [PhoneCarriage.FCStd, PhoneGrip.fcstd]
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2016-06-13 Redesign the bearing slit because of #26
    [LYcarriage.step, RYcarriage.step, Ycarriage.fcstd]
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2016-06-17 Add a lower bolt to prevent lid flexion and a MicroSpot sign to ElecHolder
    [ElecBase.step, ElecHolder.FCStd, Lid.step]
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2016-06-20 Redesign DVD2Xperia from scratch
    [DVD2Xperia.fcstd]
2016-06-21 DVD2Xperia made shorter. Camera hole repositioned. Issues #60 and
    [DVD2Xperia.fcstd]
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2016-06-21 Fix gear nut slots
2016-06-21 Fix gear distance. This fixes #58
    [MainStructure.fcstd, MainStructure.step]
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2016-06-30 Correct hexagon dimensions.
    [Thumbscrew.FCStd]
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2016-07-04 Finish first design of illuminator module, minus fixings
    [Illuminator.fcstd]
2016-07-04 Finish first design of illuminator. Make back and front fixings
    [IllumBackFix.fcstd, IllumFrontFix.fcstd, Illuminator.fcstd]
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2016-07-10 Remodel Illumination module with better collision references
    [IlluLower.step, IlluMiddle.step, IlluUpper.step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]
2016-07-10 Make new front and back fixes to the main frame
    [IllumBackFix.fcstd, IllumFrontFix.fcstd, Illuminator.fcstd]
2016-07-11 IllumBackFix collided with the ground
    [IllumBackFix.fcstd, Illuminator.fcstd]
2016-07-12 Make Xcarriage flaps shorter. This closes #73
    [Xcarriage.fcstd]
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2016-09-15 Solve assembly path errors
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2016-09-15 Adjust front and back corner inconsistencies
    Make BackCorner LowerCover walls 1mm thicker
    Cut FrontCorner LowerCover height by 0.5mm
    Make FrontCorner PlateCut 0.5mm shallower
    [BackCorner.fcstd, FrontCorner.fcstd, LBackCorner.step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]
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2016-09-15 Change the place of the top for better sample removal. This addresses #56
    [StringTensioner.fcstd]
2016-09-16 Add space for the Yendstop fixing nut
    [LowerCover.fcstd, LowerCover.step]
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2016-10-06 Redesign StringTensioner bolt support. This fixes issue #91
    [StringTensioner.fcstd]
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2016-10-10 Redesign PhoneGrip. Adjust PhoneCarriage References
    [PhoneCarriage.FCStd, PhoneGrip.fcstd]
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2016-10-24 Fix #98
    [MainStructure.step, MainStructure_new.fcstd]
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2016-10-24 Fix unprintable bearing slot in BearingHolder
    [BearingHolder.fcstd]
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2016-10-24 Redesign PhoneGrip
    [PhoneCarriage.FCStd, PhoneGrip.fcstd]
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2016-10-24 Correct the lower surface in Thu ThumbWheelHolder as in #103
    [PhoneCarriage.FCStd, ThumbWheelHolder.fcstd]
2016-10-24 Address issues #99 and #102.
    Change horizontal bolt hole shape as commented in #24
    [FrontCorner.fcstd, LowerCover.fcstd, LowerCover.step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]
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2016-10-27 Redesign StringTensioner
    [StringTensioner.fcstd]
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2016-11-03 Correct mistake in the grip main pad lengths
    [PhoneGrip.fcstd]
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2016-11-11 Split PhoneHolder in two somewhat printable parts Draft the new LensAdjust design Change tolerances in ThumbWheelHolder
    [ThumbWheelHolder.fcstd]
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2016-11-16 Add missing nut slots in LidPhoneCarriage. Correct optic slot in OpticFit
    [LidPhoneCarriage.step, UpperPhoneCarriage.step]
2016-11-16 Redesign the lens adapter template
    [LensMountTemplate.fcstd]
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2016-11-17 Adjust filament tolerances
    [OpticElbow.fcstd, OpticFit.fcstd]
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2016-11-18 Make PhoneCarriageLid 1mm taller. Export new step files and delete old ones.
    [LidPhoneCarriage.step, MainStructure.step, RodLid.step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]
2016-11-18 Adjust filament tolerances in Pho PhoneCarriage. Correct naming error in SmallShortArm
    [SmallShortArm.fcstd, UpperPhoneCarriage.step]
2016-11-21 Get rid of the arm side clearance in the optic mount
    [OpticElbow.fcstd, OpticFit.fcstd]
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2016-11-21 Adapt LowerLid to the new AxisShield. Make tube longer as in #104.
    [LowerCover.fcstd, LowerCover.step, TubeLid.step]
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2016-11-23 Fix dimension error in YCarriage
    [LYcarriage.step, RYcarriage.step, Ycarriage.fcstd]
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2016-11-25 Add more clearance to the whole spring mechanism. Add chamfers to prevent spin locks.
    [Arm.fcstd, LensSpring.fcstd]
2016-11-25 Add window closing in XCarriage to avoid #90
    [Xcarriage.fcstd]
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2016-11-29 Set arm lenght to 22. Set Dice clearance to 0. Set arm clearance to 0.1
    [Arm.fcstd, LensSpring.fcstd]
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2016-11-30 Remodel AxisShield for better grip and print direction. Make LowerCover bolts stick out a little more for better profile attachment
    [AxisShield.fcstd, LowerCover.fcstd, LowerCover.step]
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2016-12-02 Some color correction in PhoneGrip
    [PhoneGrip.fcstd]
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2016-12-19 Redesign YCarriage to address #106 #110 and #124.
    Clean up old source file, and delete unnecesary .step files.
    [BottomXCarriage.step, LYcarriage.step, MiniIdler.fcstd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]
2016-12-20 Update SampleFix design, as well as XCarriage and SampleTop
    Tighten the tolerances on XCarriage autothread bolts.
    [SampleFix.fcstd, SampleTop.fcstd]
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2016-12-21 Make guide for SampleTop. Some color corrections.
    [SampleFix.fcstd, SampleTop.fcstd]
2016-12-21 Make tolerance adjustments
    [SampleFix.fcstd, SampleTop.fcstd]
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2016-12-28 Correct YCarriage import to assembly
    [Assembly.fcstd]
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2016-12-28 Finish the redesign of the electronics box
    [ElecHolder.FCStd, ElecLid.fcstd, ElecMain.fcstd]
2016-12-29 Add a 623ZZ to the flexible bracket. Adapt PhoneArm to the flexible bracket.
    [LeafTest623ZZ.fcstd, PhoneArm.fcstd]
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2017-01-08 Make some dimension correction on LeafTests, add missing FitChamfer to LensMountTemplate
    [LeafTest.fcstd, LeafTest623ZZ.fcstd, LensMountTemplate.fcstd]
2017-01-09 Correct dimensional aspects in LeafTest. Add pads, and correct dimensions in PhoneArm. Update PhoneCarriage design.
    [LeafTest.fcstd, PhoneArm.fcstd, UpperPhoneCarriage.step]
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2017-01-10 Make AntiCreaseChamfer wider in LeafTest so the lens mount can fit more easily
    [LeafTest.fcstd]
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2017-01-10 Make LensMount 1mm shorter
    [LensMountTemplate.fcstd, PS3_BluRay.fcstd]
2017-01-11 Modify PhoneArm to address #137. Add countersunk bolts to LeafTest to address #136
    [LeafTest.fcstd, PhoneArm.fcstd]
2017-01-11 Add tightening bolts to BearingHolder
    [BearingHolder.fcstd]
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2017-01-12 Correct PS3 mounting width. Remove old source files, and rename LeafTest to LensBracket
    [LeafTest.fcstd, LeafTest623ZZ.fcstd, LensAdjust.fcstd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]
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2017-01-15 Replace DIN7991 for DIN912 in LensBracket
    [LensBracket.fcstd]
2017-01-16 Add more clearance to LensBracket so it bends properly, as in #142
    [LensBracket.fcstd]
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2017-01-24 Leave space for the finger to spin ThumbScrew in PhoneGrip, as in #155
    [PhoneGrip.fcstd]
2017-01-25 Rework Lid and Base bolts to address #145 and #146
    [ElecLid.fcstd, ElecMain.fcstd]
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2017-02-03 Correct missing fillet in LensMount
    [DVD.fcstd]
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2017-02-09 Add a MicroSpot sign to each AxisShieldd. This way it's easier to distinguish the left one from the right one.
    [AxisShield.fcstd, LAxisShield.step, RAxisShield.step]
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2017-02-17 Correct SwitchWindow as in #172
    [ElecLid.fcstd]
2017-02-17 Fix the front Chamfer. References updated to Assemblyv2 system
    [LowerCover.fcstd, LowerCover.step]
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2017-05-25 Finish first draft of magnetic XCarriage. First approximation of magnet dimensions. Fix forgotten fillet
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2017-05-30 Fix magnet holese dimensions, and tweak slider dimensions
    [SampleTray.fcstd]
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2017-06-16 Remodel sample fix system to a easier to use design
    [SampleFix.fcstd, SampleTop.fcstd, SampleTray.fcstd]
2017-06-26 Redesign SampleTray
    [SampleFix.fcstd, SampleTop.fcstd, SampleTray.fcstd]
2017-06-27 Make modifications based in user feedback. Correct bolt dimensions
    [SampleFix.fcstd, SampleTop.fcstd, SampleTray.fcstd]
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2017-07-25 Correct dimensions from several trays Add text identifying the different trays.
    [SampleFix.fcstd, SampleTop.fcstd, SampleTray.fcstd]
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2017-11-28 Correct Assembly. Update README
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2018-01-17 Update SampleTray. Remove lips from sample tops. Reorganize this part in general
    [FastReadFix.fcstd, FastReadTop.fcstd, NeubauerFix.fcstd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]
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2018-02-02 Redesign of ElecHolder, with rails
    [ElecMain.fcstd]
2018-02-02 Redesign FrontCorner and LowerCover to fit the new frame layout. Also update the design style
    [FrontCorner.fcstd, LowerCover.fcstd, TubeLid.step]
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2018-02-05 Fix stranded fillet in BackCorner
    [LBackCorner.step]
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2018-02-06 Correct drawer position on FrontCrane
    [FrontCrane.fcstd, FrontCraneGuide.step]
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2018-02-23 Fix unsunk bolts on the Corners
    [FrontCorner.fcstd, LBackCorner.step]
2018-03-01 Finish PhoneRail design. Fix MR in UpperLidRail.
    [PhoneRail.fcstd, UpperLidRail.fcstd]
2018-03-02 Design new optics fix system
    [FlexiRing.fcstd, LensFixTemplate.fcstd, OuterRing.fcstd]
2018-03-02 Fix wrong bolt placement in UpperCover
2018-03-07 Add a way to fix the drawer in the closed position. Branding relocation
    [UpperBackCover.fcstd, UpperLidRail.fcstd]
2018-03-07 Make UpperCover thinner, and the optics thicker, to get the lens closer to the sample
    [FlexiRing.fcstd, LensFixTemplate.fcstd, OuterRing.fcstd]
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2018-03-13 Fix collition in FrontGuide
    [FrontGuide.fcstd]
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2018-03-16 Add a magnet to the drawer's end. Rethink optics fixing system
    [UpperBackCover.fcstd, UpperLidRail.fcstd]
2018-03-19 Add clearances to the rails involved in the drawer mechanism
    [DrawerGuide.fcstd, UpperLidRail.fcstd]
2018-03-19 Rework optics adaptor
    [FlexiRing.fcstd, LensFixTemplate.fcstd, OuterRing.fcstd]
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2018-03-20 Increase upper clearance in FrontCrane
    [FrontCrane.fcstd]
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2018-03-21 Change tolerances in the drawer guides
    [DrawerGuide.fcstd, UpperLidRail.fcstd]
2018-04-02 Update ElecMain so it doesn't collide with UpperBackLid
    [ElecMain.fcstd]
2018-04-02 Fix collition between YCarriage and UpperLidRail
    [UpperLidRail.fcstd]
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2018-04-03 Fix NeubauerTop dimensions
    [NeubauerTop.fcstd]
2018-04-05 Fix mistake in YRodBoltCuts in BackCorner
    [LBackCorner.step]
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2018-04-19 Update UpperLid with easier optics removal, and new phone axis fixings
    [UpperCover.fcstd]
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2018-04-23 Correct FlexiRing
    [FlexiRing.fcstd]
2018-04-23 Adjust tolerances in GripFlex
    [GripFlex.fcstd]
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2018-04-23 Make floor clearance wider in LAP0704Dual
    [DualLAP0704.fcstd]
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2018-06-11 Update UpperBackCover to make place for the phone fixer
    [UpperBackCover.fcstd]
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2018-06-15 Design the frame of the phone fixer, with the ratchet
    [FixKnob.fcstd, PhoneFixFrame.fcstd, Ratchet.step]
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2018-06-18 Fix mistakes in RightGrip
    [RightGrip.fcstd]
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2018-06-19 Remodel AxisShield to make place for the new UpperCover. Add a limit that prevents the lid to be opened while it's down
    [AxisShield.fcstd, LAxisShield.step]
2018-06-19 Fix excessively thin wall in RightGrip
    [RightGrip.fcstd]
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2018-06-20 Revert some changes on UpperBackCover so it covers the new mechanisms better.
    [BackCraneGuide.step, UpperBackCover.fcstd]
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2018-06-20 Reduce UpperLidRail so it doesn't have friction with FrontCrane
    [UpperLidRail.fcstd]
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2018-06-21 Fix GuideIdler geometry. Make UpperCover nut cavities deeper
    [GuideIdler.fcstd, UpperCover.fcstd]
2018-06-22 Revert changes to GuideIdler
    [GuideIdler.fcstd]
2018-06-24 Make material reduction shallower on UpperLidRail to avoid thin walls
    [UpperLidRail.fcstd]
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2018-06-27 Redesign PhoneFixFrame for the new fixing idea.
    [PhoneFixFrame.fcstd]
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2018-06-28 Fix PhoneFixFrame bolts and parametrize PhoneGrip length
    [PhoneFixFrame.fcstd, PhoneGrip.fcstd]
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2018-06-29 Fix DrawerGuide back bolts
    [DrawerGuide.fcstd]
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2018-07-02 Correct PhoneGrip with first resistance and fitting tests
    [PhoneGrip.fcstd]
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2018-07-10 Add new tolerances to DrawerGuide to make assembly more reliable.
    [DrawerGuide.fcstd]
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2018-07-19 Redesign UpperCover and UpperBackCover to use a gel pad
    [UpperBackCover.fcstd]
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2018-07-19 Correct excessive dimension in DrawerGuide
    [DrawerGuide.fcstd]
2018-07-19 Fix mistake in UpperBackCover
    [UpperBackCover.fcstd]
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2018-07-23 Reinforce center TubeLid bolt
    [LowerCover.fcstd]
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2018-07-30 Update cable fixing in PulleyCover
    [PulleyCover.fcstd]
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2018-07-30 Correct the cable holder in PulleyCover
    [PulleyCover.fcstd]
2018-07-30 Correct the cable holder in PulleyCover once again
    [PulleyCover.fcstd]
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2018-07-31 Reinforce PulleyCover
    [PulleyCover.fcstd]
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2018-08-02 Correct Bolts
    [LAQ0201nLDB0504.fcstd]
2018-08-03 Update LAQ0202 adapter with correct geometry
    [LAQ0202.fcstd]
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2018-09-21 Revert PS2 adapter to experimental distances
    [LAQ0202nPS2.fcstd]
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2018-11-02 Add slots to TubeLid bolts to allow for illumination alignment. Make space for the FemtoBuck connector Clean up LowerCover sources a little bit.
    [LowerCover.fcstd, TubeLid.step]
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
